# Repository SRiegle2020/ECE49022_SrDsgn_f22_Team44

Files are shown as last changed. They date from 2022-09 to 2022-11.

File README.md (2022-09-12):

# ECE49022_SrDsgn_f22_Team44
ECE49022, Team44, f2022. Biometric "Smart" Watch.
This project aims to display important vital signs to a user in a self-contained watch. The device will specifically track SpO2, heart rate, temperature,
steps walked, and calories consumed. More information to be added to this README.md later.

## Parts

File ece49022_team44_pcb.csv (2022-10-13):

Comment | Designator | Footprint | LCSC PART NUMBER
10n | C1,C2 | Capacitor_SMD:C_0201_0603Metric | C285010
33uF | C19 | Capacitor_Tantalum_SMD:CP_EIA-3528-21_Kemet-B | C723311
22uF | C21,C22 | Capacitor_SMD:C_0402_1005Metric | C415703
0.1uF | C3,C4,C6,C7,C8,C9,C10,C11,C12,C13,C14,C15,C16 | Capacitor_SMD:C_0201_0603Metric | C284966
10uF | C5,C17,C18,C20,C23,C24,C25 | Capacitor_SMD:C_0402_1005Metric | C163694
1N4007 | D1 | Diode_SMD:D_SMA | C727081
LED_Small | D2,D3,D7,D8,D9,D10 | LED_SMD:LED_0603_1608Metric | C72043
BAT60JFILM | D4,D5,D6 | Diode_SMD:D_SOD-323 | C133103
USB_C_Receptacle_USB2.0 | J6 | Connector_USB:USB_C_Receptacle_XKB_U262-16XN-4BVC11 | C2927038
Conn_01x02 | J7,J8 | Connector_JST:JST_PH_S2B-PH-K_1x02_P2.00mm_Horizontal | C265016
SolderJumper_3_Bridged12 | JP1,JP2,JP3,JP4 | Jumper:SolderJumper-3_P1.3mm_Bridged12_Pad1.0x1.5mm
SolderJumper_2_Bridged | JP5 | Jumper:SolderJumper-2_P1.3mm_Bridged2Bar_Pad1.0x1.5mm
1.5uH | L1 | Inductor_SMD:L_0805_2012Metric | C281090
MMBT3904 | Q1 | Package_TO_SOT_SMD:SOT-23 | C8512
BC547 | Q2 | Package_TO_SOT_THT:TO-92_Inline | C713613
10k | R1,R2,R19 | Resistor_SMD:R_0201_0603Metric | C473048
1M | R10 | Resistor_SMD:R_0402_1005Metric | C26083
178k | R11 | Resistor_SMD:R_0402_1005Metric | C185459
680 | R12 | Resistor_SMD:R_0201_0603Metric | C473509
3.3 | R13 | Resistor_SMD:R_0603_1608Metric | C22979
1k | R14 | Resistor_SMD:R_0201_0603Metric | C102683
2.2k | R17 | Resistor_SMD:R_0201_0603Metric | C142018
470 | R18,R20 | Resistor_SMD:R_0201_0603Metric | C473464
150 | R3,R8,R9,R15,R16 | Resistor_SMD:R_0201_0603Metric | C246814
100k | R4,R5 | Resistor_SMD:R_0201_0603Metric | C270364
15k | R6 | Resistor_SMD:R_0201_0603Metric | C473455
220k | R7 | Resistor_SMD:R_0603_1608Metric | C22961
RotaryEncoder_Switch | SW1 | Rotary_Encoder:RotaryEncoder_Alps_EC11E-Switch_Vertical_H20mm_CircularMountingHoles | C370986
Reset | SW2 | Button_Switch_SMD:SW_SPST_Omron_B3FS-101xP | C271753
SW_SPST | SW3 | Button_Switch_SMD:SW_DIP_SPSTx01_Slide_Copal_CHS-01B_W7.62mm_P1.27mm | C3293141
STM32F091RCTx | U1 | Package_QFP:LQFP-64_10x10mm_P0.5mm | C89056
LD1117S33TR_SOT223 | U10 | Package_TO_SOT_SMD:SOT-223-3_TabPin2 | C35879
MCP73831-2-OT | U11,U12 | Package_TO_SOT_SMD:SOT-23-5 | C424093
HDC1080 | U2 | Package_SON:Texas_PWSON-N6 | C82227
PCA9306DC | U4 | Package_SO:VSSOP-8_2.3x2mm_P0.5mm | C33196
PCF8523T | U5 | Package_SO:SOIC-8_3.9x4.9mm_P1.27mm | C2651516
MAX30102 | U6 | OptoDevice:Maxim_OLGA-14_3.3x5.6mm_P0.8mm | C9900007468
MPU-6050 | U7 | Sensor_Motion:InvenSense_QFN-24_4x4mm_P0.5mm | C24112
TPS63000-Q1 | U8 | Package_SON:Texas_DRC0010J_ThermalVias | C523783
LM1117-1.8 | U9 | Package_TO_SOT_SMD:TO-252-2 | C38160

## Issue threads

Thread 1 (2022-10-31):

Display Refresh

SRiegle2020, 2022-10-31:
Must reinit display to refresh screen. Likely due to accelerometer or SpO2 data sampling or processing. Any way to do I2C/DMA with multiple devices on same bus?

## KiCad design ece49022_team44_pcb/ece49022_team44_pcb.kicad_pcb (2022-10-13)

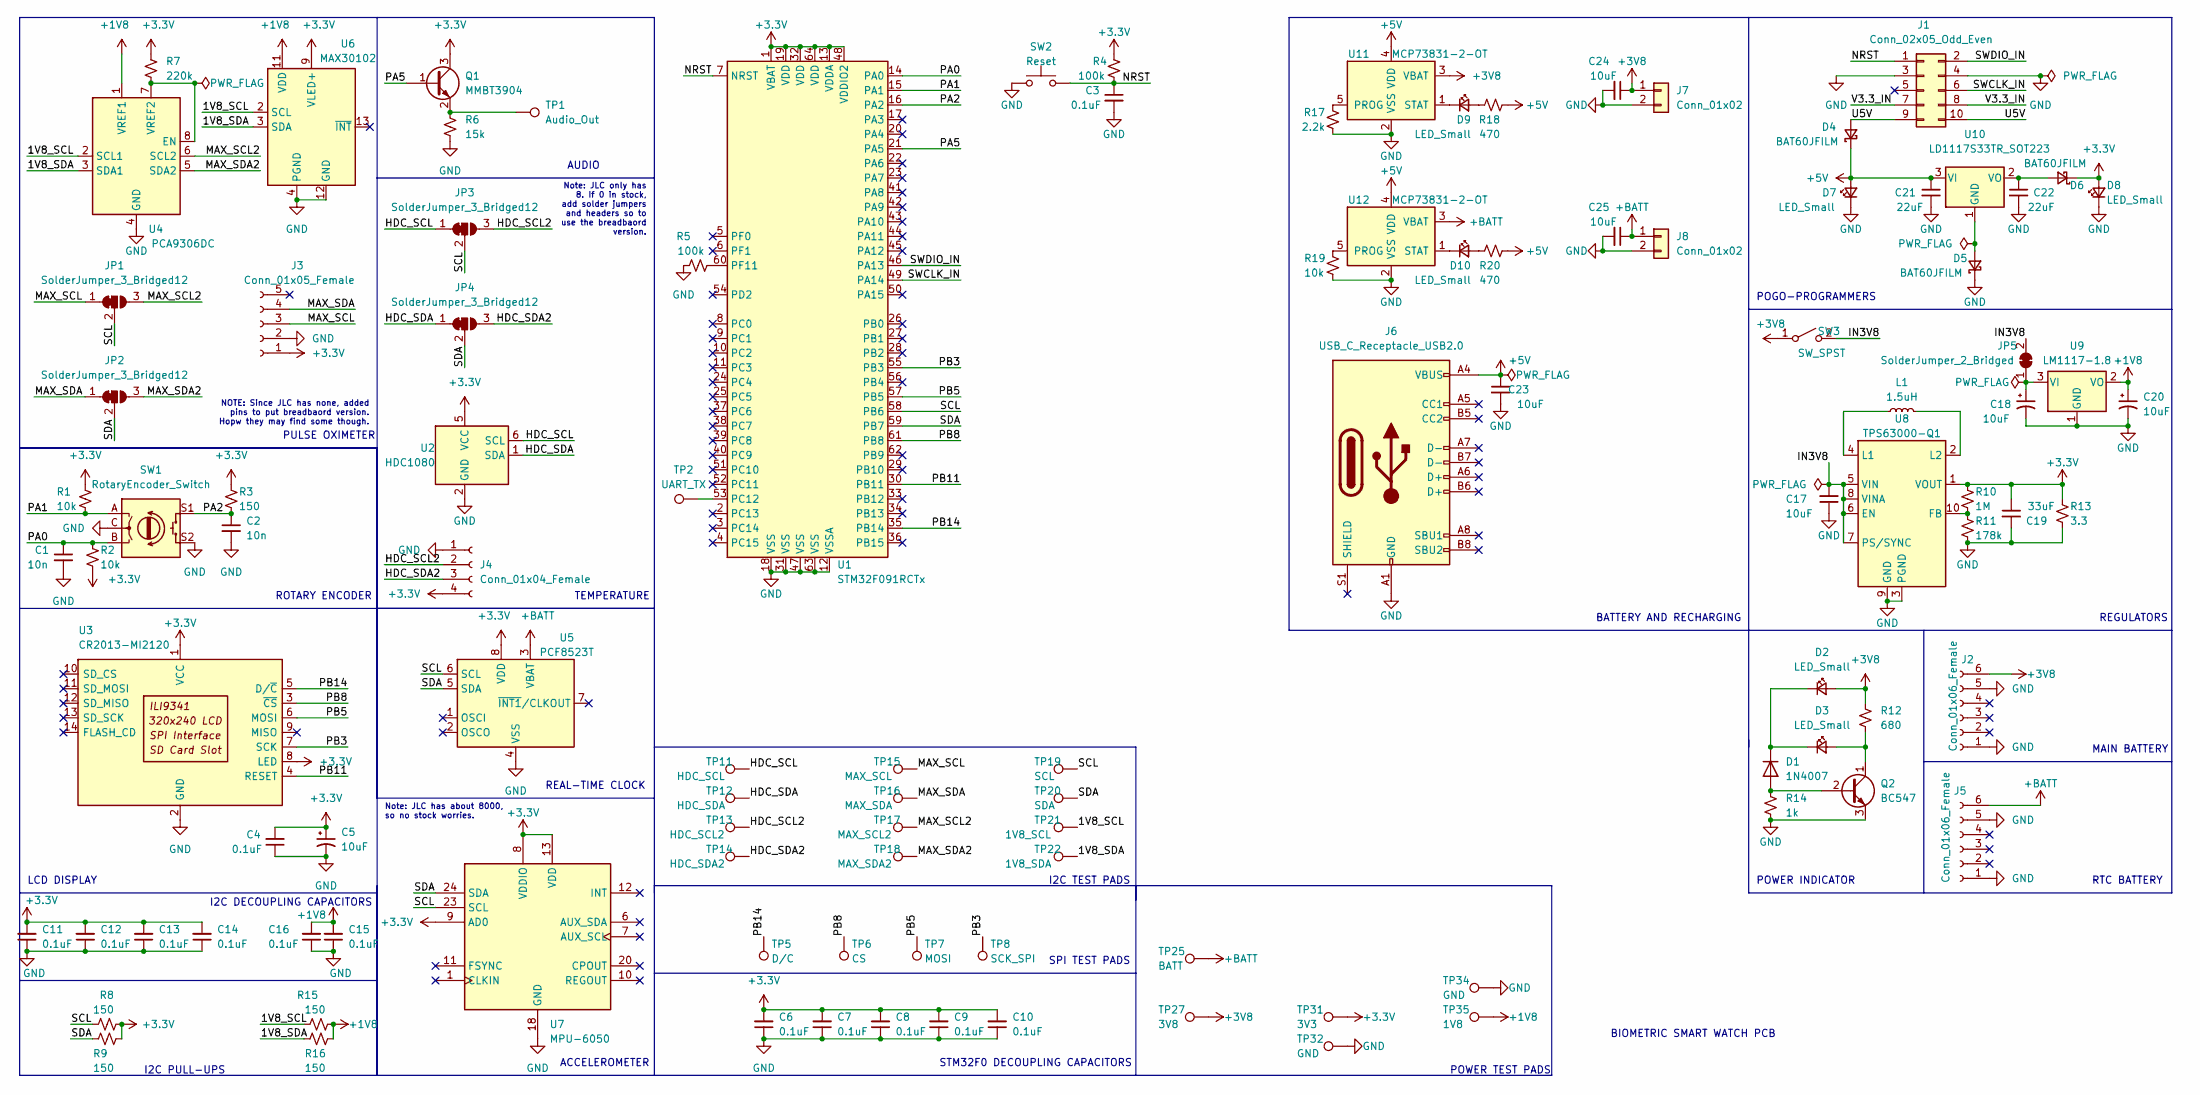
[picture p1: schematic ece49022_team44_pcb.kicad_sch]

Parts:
C1, C2: 10n; C_0201_0603Metric; LCSC C285010
C3, C4, C6, C7, C8, C9, C10, C11, C12, C13, C14, C15, C16: 0.1uF; C_0201_0603Metric; LCSC C284966
C5, C17, C18, C20, C23, C24, C25: 10uF; C_0402_1005Metric; LCSC C163694
C19: 33uF; CP_EIA-3528-21_Kemet-B; LCSC C723311
C21, C22: 22uF; C_0402_1005Metric; LCSC C415703
D1: 1N4007; D_SMA; LCSC C727081
D2: LED_Small; LED_0603_1608Metric; LCSC C72043
D3: LED_Small; LED_0603_1608Metric; LCSC C2286
D4, D5, D6: BAT60JFILM; D_SOD-323; LCSC C133103
D7, D8, D9, D10: LED_Small; LED_0603_1608Metric; LCSC C72038
J1: Conn_02x05_Odd_Even; Tag-Connect_TC2050-IDC-NL_2x05_P1.27mm_Vertical
J2, J5: Conn_01x06_Female; PinSocket_1x06_P2.54mm_Vertical
J3: Conn_01x05_Female; PinSocket_1x05_P2.54mm_Vertical
J4: Conn_01x04_Female; PinHeader_1x04_P2.54mm_Vertical
J6: USB_C_Receptacle_USB2.0; USB_C_Receptacle_XKB_U262-16XN-4BVC11; LCSC C2927038
J7, J8: Conn_01x02; JST_PH_S2B-PH-K_1x02_P2.00mm_Horizontal; LCSC C265016
JP1, JP2, JP3, JP4: SolderJumper_3_Bridged12; SolderJumper-3_P1.3mm_Bridged12_Pad1.0x1.5mm
JP5: SolderJumper_2_Bridged; SolderJumper-2_P1.3mm_Bridged2Bar_Pad1.0x1.5mm
L1: 1.5uH; L_0805_2012Metric; LCSC C281090
Q1: MMBT3904; SOT-23; LCSC C8512
Q2: BC547; TO-92_Inline; LCSC C713613
R1, R2, R19: 10k; R_0201_0603Metric; LCSC C473048
R3, R8, R9, R15, R16: 150; R_0201_0603Metric; LCSC C246814
R4, R5: 100k; R_0201_0603Metric; LCSC C270364
R6: 15k; R_0201_0603Metric; LCSC C473455
R7: 220k; R_0603_1608Metric; LCSC C22961
R10: 1M; R_0402_1005Metric; LCSC C26083
R11: 178k; R_0402_1005Metric; LCSC C185459
R12: 680; R_0201_0603Metric; LCSC C473509
R13: 3.3; R_0603_1608Metric; LCSC C22979
R14: 1k; R_0201_0603Metric; LCSC C102683
R17: 2.2k; R_0201_0603Metric; LCSC C142018
R18, R20: 470; R_0201_0603Metric; LCSC C473464
SW1: RotaryEncoder_Switch; RotaryEncoder_Alps_EC11E-Switch_Vertical_H20mm_CircularMoun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; LCSC C370986
SW2: Reset; SW_SPST_Omron_B3FS-101xP; LCSC C271753
SW3: SW_SPST; SW_DIP_SPSTx01_Slide_Copal_CHS-01B_W7.62mm_P1.27mm; LCSC C3293141
TP1: Audio_Out; TestPoint_Pad_D2.5mm
TP2: UART_TX; TestPoint_Pad_D2.5mm
TP5: D/C; TestPoint_Pad_D2.5mm
TP6: CS; TestPoint_Pad_D2.5mm
TP7: MOSI; TestPoint_Pad_D2.5mm
TP8: SCK_SPI; TestPoint_Pad_D2.5mm
TP11: HDC_SCL; TestPoint_Pad_D2.5mm
TP12: HDC_SDA; TestPoint_Pad_D2.5mm
TP13: HDC_SCL2; TestPoint_Pad_D2.5mm
TP14: HDC_SDA2; TestPoint_Pad_D2.5mm
TP15: MAX_SCL; TestPoint_Pad_D2.5mm
TP16: MAX_SDA; TestPoint_Pad_D2.5mm
TP17: MAX_SCL2; TestPoint_Pad_D2.5mm
TP18: MAX_SDA2; TestPoint_Pad_D2.5mm
TP19: SCL; TestPoint_Pad_D2.5mm
TP20: SDA; TestPoint_Pad_D2.5mm
TP21: 1V8_SCL; TestPoint_Pad_D2.5mm
TP22: 1V8_SDA; TestPoint_Pad_D2.5mm
TP25: BATT; TestPoint_Pad_D2.5mm
TP27: 3V8; TestPoint_Pad_D2.5mm
TP31: 3V3; TestPoint_Pad_D2.5mm
TP32, TP34: GND; TestPoint_Pad_D2.5mm
TP35: 1V8; TestPoint_Pad_D2.5mm
U1: STM32F091RCTx; LQFP-64_10x10mm_P0.5mm; LCSC C89056
U2: HDC1080; Texas_PWSON-N6; LCSC C82227
U3: CR2013-MI2120
U4: PCA9306DC; VSSOP-8_2.3x2mm_P0.5mm; LCSC C33196
U5: PCF8523T; SOIC-8_3.9x4.9mm_P1.27mm; LCSC C2651516
U6: MAX30102; Maxim_OLGA-14_3.3x5.6mm_P0.8mm; LCSC C9900007468
U7: MPU-6050; InvenSense_QFN-24_4x4mm_P0.5mm; LCSC C24112
U8: TPS63000-Q1; Texas_DRC0010J_ThermalVias; LCSC C523783
U9: LM1117-1.8; TO-252-2; LCSC C38160
U10: LD1117S33TR_SOT223; SOT-223-3_TabPin2; LCSC C35879
U11, U12: MCP73831-2-OT; SOT-23-5; LCSC C424093

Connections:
+1V8: C15.2, C16.2, C20.1, R15.1, R16.2, TP35.1, U4.1 (VREF1), U6.11 (VDD), U9.2 (VO)
+3V3: C4.2, C5.1, C6.2, C7.2, C8.2, C9.2, C10.2, C11.2, C12.2, C13.2, C14.2, C19.1, D6.1 (K), D8.2 (A), J3.1, J4.4, Q1.3 (C), R1.2, R2.1, R3.2, R4.1, R7.1, R8.1, R9.2, R10.1, R13.1, TP31.1, U1.1 (VBAT), U1.13 (VDDA), U1.19 (VDD), U1.32 (VDD), U1.48 (VDDIO2), U1.64 (VDD), U2.5 (VCC), U3.1 (VCC), U3.8 (LED), U5.8 (VDD), U6.9 (VLED+), U6.10 (VLED+), U7.8 (VDDIO), U7.9 (AD0), U7.13 (VDD), U8.1 (VOUT)
+3V8: C24.1, D2.2 (A), J2.6, J7.1, R12.1, SW3.1 (A), TP27.1, U11.3 (VBAT)
+5V: C21.1, C23.1, D4.1 (K), D7.2 (A), J6.A4 (VBUS), J6.A9 (VBUS), J6.B4 (VBUS), J6.B9 (VBUS), R18.2, R20.1, U10.3 (VI), U11.4 (VDD), U12.4 (VDD)
+BATT: C25.1, J5.6, J8.1, TP25.1, U5.3 (VBAT), U12.3 (VBAT)
/1V8_SCL: R15.2, TP21.1, U4.2 (SCL1), U6.2 (SCL)
/1V8_SDA: R16.1, TP22.1, U4.3 (SDA1), U6.3 (SDA)
/HDC_SCL: JP3.1 (A), TP11.1, U2.6 (SCL)
/HDC_SCL2: J4.2, JP3.3 (B), TP13.1
/HDC_SDA: JP4.1 (A), TP12.1, U2.1 (SDA)
/HDC_SDA2: J4.3, JP4.3 (B), TP14.1
/IN3V8: C17.2, JP5.2 (B), SW3.2 (B), U8.5 (VIN), U8.6 (EN), U8.7 (PS/SYNC), U8.8 (VINA)
/MAX_SCL: J3.3, JP1.1 (A), TP15.1
/MAX_SCL2: JP1.3 (B), TP17.1, U4.6 (SCL2)
/MAX_SDA: J3.4, JP2.1 (A), TP16.1
/MAX_SDA2: JP2.3 (B), TP18.1, U4.5 (SDA2)
/NRST: C3.1, J1.1, R4.2, SW2.2, U1.7 (NRST)
/PA0: C1.1, R2.2, SW1.B, U1.14 (PA0)
/PA1: R1.1, SW1.A, U1.15 (PA1)
/PA2: C2.1, R3.1, SW1.S1, U1.16 (PA2)
/PA5: Q1.1 (B), U1.21 (PA5)
/PB3: TP8.1, U1.55 (PB3), U3.7 (SCK)
/PB5: TP7.1, U1.57 (PB5), U3.6 (MOSI)
/PB8: TP6.1, U1.61 (PB8), U3.3 (~CS)
/PB11: U1.30 (PB11), U3.4 (RESET)
/PB14: TP5.1, U1.35 (PB14), U3.5 (D/~C)
/SCL: JP1.2 (C), JP3.2 (C), R8.2, TP19.1, U1.58 (PB6), U5.6 (SCL), U7.23 (SCL)
/SDA: JP2.2 (C), JP4.2 (C), R9.1, TP20.1, U1.59 (PB7), U5.5 (SDA), U7.24 (SDA)
/SWCLK_IN: J1.6, U1.49 (PA14)
/SWDIO_IN: J1.2, U1.46 (PA13)
/U5V: D4.2 (A), J1.9, J1.10
/V3.3_IN: J1.7, J1.8
GND: C1.2, C2.2, C3.2, C4.1, C5.2, C6.1, C7.1, C8.1, C9.1, C10.1, C11.1, C12.1, C13.1, C14.1, C15.1, C16.1, C17.1, C18.2, C19.2, C20.2, C21.2, C22.2, C23.2, C24.2, C25.2, D5.1 (K), D7.1 (K), D8.1 (K), J1.3, J1.4, J2.1, J2.5, J3.2, J4.1, J5.1, J5.5, J6.A1 (GND), J6.A12 (GND), J6.B1 (GND), J6.B12 (GND), J7.2, J8.2, Q2.3 (E), R5.2, R6.2, R11.2, R13.2, R14.2, R17.1, R19.1, SW1.C, SW1.S2, SW2.1, TP32.1, TP34.1, U1.12 (VSSA), U1.18 (VSS), U1.31 (VSS), U1.47 (VSS), U1.63 (VSS), U2.2 (GND), U3.2 (GND), U4.4 (GND), U5.4 (VSS), U6.4 (PGND), U6.12 (GND), U7.18 (GND), U8.3 (PGND), U8.9 (GND), U8.11 (PGND), U9.1 (GND), U11.2 (VSS), U12.2 (VSS)
unnamed: C18.1, JP5.1 (A), U9.3 (VI)
unnamed: C22.1, D6.2 (A), U10.2 (VO)
unnamed: D1.1 (A), Q2.2 (B), R14.1
unnamed: D1.2 (K), D2.1 (K), D3.1 (K)
unnamed: D3.2 (A), Q2.1 (C), R12.2
unnamed: D5.2 (A), U10.1 (GND)
unnamed: D9.1 (K), U11.1 (STAT)
unnamed: D9.2 (A), R18.1
unnamed: D10.1 (K), U12.1 (STAT)
unnamed: D10.2 (A), R20.2
unnamed: L1.1, U8.4 (L1)
unnamed: L1.2, U8.2 (L2)
unnamed: Q1.2 (E), R6.1, TP1.1
unnamed: R5.1, U1.60 (PF11)
unnamed: R7.2, U4.7 (VREF2), U4.8 (EN)
unnamed: R10.2, R11.1, U8.10 (FB)
unnamed: R17.2, U11.5 (PROG)
unnamed: R19.2, U12.5 (PROG)
unnamed: TP2.1, U1.53 (PC12)

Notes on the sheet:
POGO-PROGRAMMERS
BATTERY AND RECHARGING
Note: JLC only has 8. If 0 in stock, add solder jumpers and headers so to use the breadbaord version.
TEMPERATURE
REAL-TIME CLOCK
NOTE: Since JLC has none, added pins to put breadbaord version. Hopw they may find some though.
SPI TEST PADS
MAIN BATTERY
RTC BATTERY
I2C PULL-UPS
REGULATORS
ROTARY ENCODER
BIOMETRIC SMART WATCH PCB
I2C TEST PADS
Note: JLC has about 8000, so no stock worries.
POWER INDICATOR
PULSE OXIMETER
LCD DISPLAY
I2C DECOUPLING CAPACITORS
ACCELEROMETER
STM32F0 DECOUPLING CAPACITORS
AUDIO
POWER TEST PADS

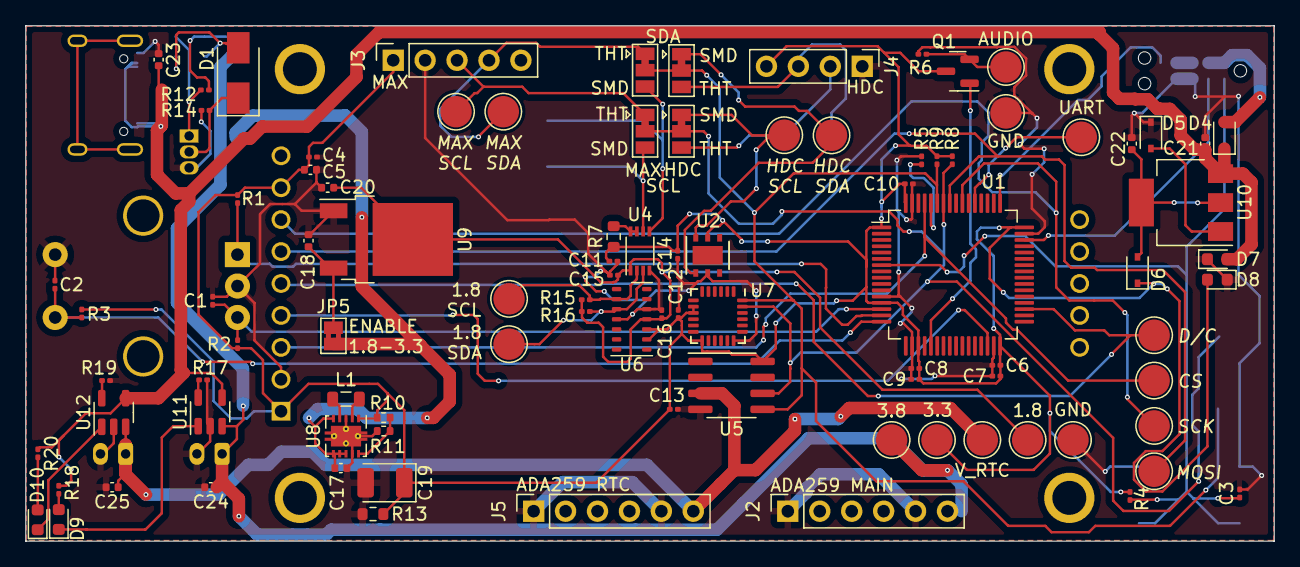
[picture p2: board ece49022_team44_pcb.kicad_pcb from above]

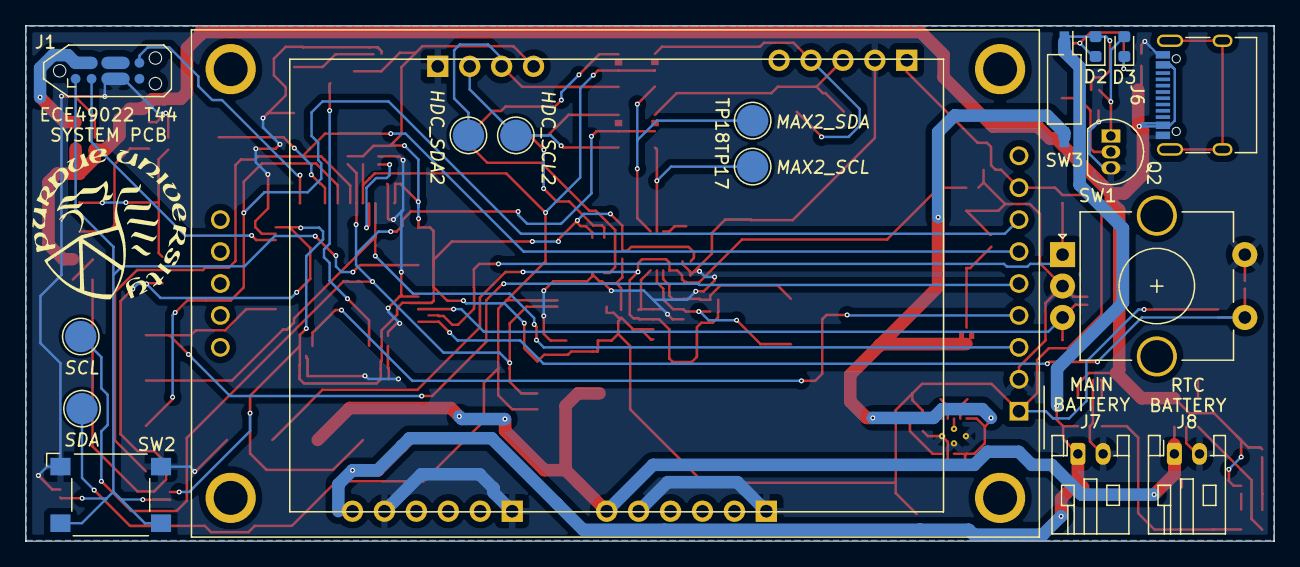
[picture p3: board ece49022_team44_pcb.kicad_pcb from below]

Board: 2 copper layers, 99.3 x 41.0 mm, 110 parts (17 on the bottom side), 52 nets.

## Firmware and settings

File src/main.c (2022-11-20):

//==============================================================================
// DEFINE LIBRARIES
//	Define all libraries to be used for the project.
//==============================================================================
#include "stm32f0xx.h"
#include "i2c.h"
#include "uart.h"
#include "rtc.h"
#include "accelerometer_algorithms.h"
#include "sensors.h"
#include "lcd.h"

#define NO_INIT_GCC __attribute__ ((section (".noinit")))

//==============================================================================
// DEFINE TEST CASES
//	Will be useful if needing UART debugging
//==============================================================================
#define TEST_NONE	 0x00
#define TEST_SPO2 	 0x01
#define TEST_STEP    0x02
#define TEST_EE		 0x04
#define TEST_TIME	 0x10
#define TEST_HR	     0x20
#define TEST_ENCODER 0x40
#define TEST_TEMP	 0x80
#define TEST_AUDIO   0x100
#define TEST_ALL    TEST_SPO2 | TEST_STEP | TEST_EE | TEST_TIME | TEST_HR | TEST_ENCODER | TEST_AUDIO
#define CS_HIGH do { GPIOB->BSRR = GPIO_BSRR_BS_8; } while(0)

//IMPORTANT ==> Change this to change what tests you are running with the UART
int tests = TEST_NONE;

//==============================================================================
// INITIALIZE GLOBAL VARIABLES
//	Initializes all variables that will be used for the project.
//==============================================================================
int   i	  			= 0;
int   prev_spo2 	= 0;
int   spo2  		= 0;
int   prev_HR   	= 0;
int   HR			= 0;
int   prev_tempF 	= 0;
int   tempF  		= 0;
int   prev_steps    = 0;
int   steps 	    = 0;
int   prev_EE_a     = 0;
int   EE_a  		= 0;
int	  prev_hour     = 0;
int   hour			= 0;
int   prev_minute   = 0;
int   minute  		= 0;

static int  ft   NO_INIT_GCC;
static int  inch NO_INIT_GCC;
static int  wgt  NO_INIT_GCC;
static int  age  NO_INIT_GCC;
static char sex  NO_INIT_GCC;
static char string[20];

int mode = 0;

static inline void nano_wait(unsigned int n) {
    asm(    "        mov r0,%0\n"
            "repeat: sub r0,#83\n"
            "        bgt repeat\n" : : "r"(n) : "r0", "cc");
}

void init_exti(void) {
    RCC->AHBENR  |=  RCC_AHBENR_GPIOAEN;            //Clock GPIOA
    GPIOA->MODER &= ~(GPIO_MODER_MODER0             //Configure PA0-2 as inputs
                    | GPIO_MODER_MODER1
                    | GPIO_MODER_MODER2);
    GPIOA->MODER |= GPIO_MODER_MODER5_0;            //Set PA5 to output
    GPIOA->PUPDR &= ~(GPIO_PUPDR_PUPDR0             //Set PUPDR
                    | GPIO_PUPDR_PUPDR1);
    GPIOA->PUPDR |=  (GPIO_PUPDR_PUPDR0_0
                    | GPIO_PUPDR_PUPDR1_0);

    RCC->APB2ENR      |=  RCC_APB2ENR_SYSCFGCOMPEN;         //Clock the interrupt
    SYSCFG->EXTICR[1] &= ~(SYSCFG_EXTICR1_EXTI0_PA
                         | SYSCFG_EXTICR1_EXTI2_PA);        //Set to PA0, PA2
    EXTI->IMR         |=  EXTI_IMR_MR0 | EXTI_IMR_MR2;      //Unmask the interrupts for PA0,PA2
    EXTI->RTSR        |=  EXTI_RTSR_TR0;                    //Set to both rising and falling edge for PA0
    EXTI->FTSR        |=  EXTI_FTSR_TR0;
    EXTI->RTSR        |=  EXTI_RTSR_TR2;                    //Set to rising edge for PA2 (changes when button is RELEASED)

    NVIC->ISER[0] = 1 << EXTI0_1_IRQn;
    NVIC->ISER[0] = 1 << EXTI2_3_IRQn;  //Enable the interrupts
}

//============================================================================
// CHECK_VITALS
//  * Check if user vitals are healthy. If not, play alert tone.
//============================================================================
void check_vitals(void) {
	if((tempF > 991 || (spo2 < 95) || HR < 60 || HR > 100) && spo2 > 0)
		TIM7->CR1 |=  TIM_CR1_CEN;
	else
		TIM7->CR1 &= ~TIM_CR1_CEN;

	if(tests & TEST_AUDIO)
		TIM7->CR1 |=  TIM_CR1_CEN;
	return;
}

//==============================================================================
// EXTI2_3_IRQHandler
//  * Uses an EXTI for PA2 to detect if the encoder button was pressed.
//  * Cycles through the different configuration settings before returning to
//    display.
//==============================================================================
void EXTI2_3_IRQHandler(void) {
    EXTI->PR |= EXTI_PR_PR2;                            //Acknowledge the interrupt
    TIM6->CR1 &= ~TIM_CR1_CEN;
    TIM2->CR1 &= ~TIM_CR1_CEN;
    mode++;
    nano_wait(100000000); //Add a delay to account for "double presses"
    //Change modes
    if(mode == 1) {
        LCD_Setup();
        LCD_DrawFillRectangle(0,214,319,239,WHITE);
        LCD_DrawString(10,219,BLACK,BLACK,"--ADJUST HGT (FEET)--",16,0xff);
        sprintf(string,"%d'",ft);
        LCD_DrawString(280,219,BLACK,BLACK,string,16,0xff);
    } else if(mode == 2) {
        LCD_DrawFillRectangle(0,214,319,239,WHITE);
        LCD_DrawString(10,219,BLACK,BLACK,"--ADJUST HGT (INCH)--",16,0xff);
        sprintf(string,"%2d'",inch);
        LCD_DrawString(280,219,BLACK,BLACK,string,16,0xff);
    } else if(mode == 3) {
        LCD_DrawFillRectangle(0,214,319,239,WHITE);
        LCD_DrawString(10,219,BLACK,BLACK,"--ADJUST WGT--",16,0xff);
        sprintf(string,"%d lbs",wgt);
        LCD_DrawString(260,219,BLACK,BLACK,string,16,0xff);
    } else if(mode == 4) {
        LCD_DrawFillRectangle(0,214,319,239,WHITE);
        LCD_DrawString(10,219,BLACK,BLACK,"--ADJUST AGE--",16,0xff);
        sprintf(string,"%d yrs",age);
        LCD_DrawString(260,219,BLACK,BLACK,string,16,0xff);
    } else if(mode == 5) {
        LCD_DrawFillRectangle(0,214,319,239,WHITE);
        LCD_DrawString(10,219,BLACK,BLACK,"--ADJUST SEX--",16,0xff);
        sprintf(string,"%c",sex);
        LCD_DrawString(280,219,BLACK,BLACK,string,16,0xff);
    } else if(mode == 6) {
        LCD_DrawFillRectangle(0,214,319,239,WHITE);
        LCD_DrawString(10,219,BLACK,BLACK,"--ADJUST TIME (HRS)--",16,0xff);
        sprintf(string,"%02d:%02d",hour,minute);
        LCD_DrawString(280,219,BLACK,BLACK,string,16,0xff);
    } else if(mode == 7) {
        LCD_DrawFillRectangle(0,214,319,239,WHITE);
        LCD_DrawString(10,219,BLACK,BLACK,"--ADJUST TIME (MIN)--",16,0xff);
        sprintf(string,"%02d:%02d",hour,minute);
        LCD_DrawString(280,219,BLACK,BLACK,string,16,0xff);

    //If done editing, redraw entire thing
    } else {
        mode = 0;
        set_hours(hour);
        set_minutes(minute);
        LCD_Setup();
        LCD_Clear(0x18e4);
        sprintf(string,"%02d:%02d",hour,minute);
        LCD_DrawString(104,96,0xf924,BLACK,string,48,0xff);

        LCD_DrawFillRectangle(0, 0, 320, 6, 0xa65b);
        LCD_DrawFillRectangle(0, 0, 6, 240, 0xa65b);
        LCD_DrawFillRectangle(0, 234, 320, 240, 0xa65b);
        LCD_DrawFillRectangle(314, 0, 320, 240, 0xa65b);

        sprintf(string,"SpO2");
        LCD_DrawString(10 + 112,10,WHITE,WHITE,string,16,0xff);
        sprintf(string,"HR");
        LCD_DrawString(10 + 180,10,WHITE,WHITE,string,16,0xff);

        if(spo2 != -1) {
            sprintf(string,"%-3d%%",spo2);
            LCD_DrawString(10 + 112,10 + 16,WHITE,WHITE,string,16,0xff);
            sprintf(string,"%-3d",HR);
            LCD_DrawString(10 + 180,10+16,WHITE,WHITE,string,16,0xff);
        } else {
            LCD_DrawString(10 + 112,10+16,WHITE,WHITE,"N/A",16,0xff);
            LCD_DrawString(10 + 180,10+16,WHITE,WHITE,"N/A",16,0xff);
        }

        sprintf(string,"TEMP");
        LCD_DrawString(10 + 235,10,WHITE,WHITE,string,16,0xff);
        sprintf(string,"%d.%d^F",tempF/10,tempF%10);
        LCD_DrawString(10 + 235,10 + 16,WHITE,WHITE,string,16,0xff);

        sprintf(string,"STEPS");
        LCD_DrawString(10,10,WHITE,WHITE,string,16,0xff);
        sprintf(string,"%-5d",steps);
        LCD_DrawString(10,10+16,WHITE,WHITE,string,16,0xff);

        sprintf(string,"EE");            //Truncate to Int
        LCD_DrawString(10 + 64,10,WHITE,WHITE,string,16,0xff);
        sprintf(string,"%-4d",EE_a/100);
        LCD_DrawString(10 + 64,10 + 16,WHITE,WHITE,string,16,0xff);

        sprintf(string,"HEIGHT");
        LCD_DrawString(100,213,WHITE,WHITE,string,16,0xff);
        sprintf(string,"%d'%2d\"",ft,inch);
        LCD_DrawString(100,197,WHITE,WHITE,string,16,0xff);

        sprintf(string,"WEIGHT",wgt);
        LCD_DrawString(10,213,WHITE,WHITE,string,16,0xff);
        sprintf(string,"%-3dlbs",wgt);
        LCD_DrawString(10,197,WHITE,WHITE,string,16,0xff);

        sprintf(string,"Age");
        LCD_DrawString(200,213,WHITE,WHITE,string,16,0xff);
        sprintf(string,"%-3d",age);
        LCD_DrawString(200,197,WHITE,WHITE,string,16,0xff);

        sprintf(string,"Sex");
        LCD_DrawString(280,213,WHITE,WHITE,string,16,0xff);
        sprintf(string,"%c",sex);
        LCD_DrawString(280,197,WHITE,WHITE,string,16,0xff);

        //Update previous values
        prev_minute = minute;
        prev_spo2   = spo2;
        prev_HR     = HR;
        prev_tempF  = tempF;
        prev_steps  = steps;
        prev_EE_a   = EE_a;

        TIM6->CR1 |= TIM_CR1_CEN;
        TIM2->CR1 |= TIM_CR1_CEN;
    }

    //Used for UART Debugging
    if(tests & TEST_ENCODER)
        printf("Button Released\n");

}

//==============================================================================
// EXTI0_1_IRQHandler
//  * Uses an EXTI for PA0 and PA1 to detect whether encoder is rotated.
//  * Changes settings based off of different modes.
//==============================================================================
void EXTI0_1_IRQHandler(void) {
    EXTI->PR |= EXTI_PR_PR0; //Acknowledge the interrupt
    int increment;
    if(!((GPIOA->IDR & 0x3)%3))
        increment = 1;
    else
        increment = -1;

    if(mode == 1) {
        ft += increment;
        //Keep values in the range [0,9]
        if(ft < 0)
            ft = 0;
        if(ft > 9)
            ft = 9;
        LCD_DrawFillRectangle(0,214,319,239,WHITE);
        LCD_DrawString(10,219,BLACK,BLACK,"--ADJUST HGT (FEET)--",16,0xff);
        sprintf(string,"%d'",ft);
        LCD_DrawString(280,219,BLACK,BLACK,string,16,0xff);
        RTC->BKP0R = ft;
    } else if(mode == 2) {
        inch += increment;
        //Keep values in the range [0,12)
        if(inch < 0)
            inch = 0;
        if(inch > 11)
            inch = 11;
        LCD_DrawFillRectangle(0,214,319,239,WHITE);
        LCD_DrawString(10,219,BLACK,BLACK,"--ADJUST HGT (INCH)--",16,0xff);
        sprintf(string,"%2d'",inch);
        LCD_DrawString(280,219,BLACK,BLACK,string,16,0xff);
        RTC->BKP1R = inch;
    } else if(mode == 3) {
        wgt += increment;
        if(wgt < 50)  //Keep values in range [50,600] to account for kids and
                      //very big people
            wgt = 50;
        if(wgt > 600)
            wgt = 600;
        LCD_DrawFillRectangle(0,214,319,239,WHITE);
        LCD_DrawString(10,219,BLACK,BLACK,"--ADJUST WGT--",16,0xff);
        sprintf(string,"%d lbs",wgt);
        LCD_DrawString(260,219,BLACK,BLACK,string,16,0xff);
        RTC->BKP2R = wgt;
    } else if(mode == 4) {
        age += increment;
        if(age < 0)     //Limit ages to [0,110]
            age = 0;
        if(age > 110)
            age = 110;
        LCD_DrawFillRectangle(0,214,319,239,WHITE);
        LCD_DrawString(10,219,BLACK,BLACK,"--ADJUST AGE--",16,0xff);
        sprintf(string,"%d yrs",age);
        LCD_DrawString(260,219,BLACK,BLACK,string,16,0xff);
        RTC->BKP3R = age;
    } else if(mode == 5) {
        if(sex == 'M')
            sex = 'F';
        else
            sex = 'M';
        LCD_DrawFillRectangle(0,214,319,239,WHITE);
        LCD_DrawString(10,219,BLACK,BLACK,"--ADJUST SEX--",16,0xff);
        sprintf(string,"%c",sex);
        LCD_DrawString(280,219,BLACK,BLACK,string,16,0xff);
        RTC->BKP4R = sex;
    } else if(mode == 6) {
        hour += increment;
        if(hour > 23)
            hour = 0;
        if(hour < 0)
            hour = 23;
        LCD_DrawFillRectangle(0,214,319,239,WHITE);
        LCD_DrawString(10,219,BLACK,BLACK,"--ADJUST TIME (HRS)--",16,0xff);
        sprintf(string,"%02d:%02d",hour,minute);
        LCD_DrawString(280,219,BLACK,BLACK,string,16,0xff);
        //TimeHr
    } else if(mode == 7) {
        //TimMin
        minute += increment;
        if(minute > 59)
            minute = 0;
        if(minute < 0)
            minute = 59;
        LCD_DrawFillRectangle(0,214,319,239,WHITE);
        LCD_DrawString(10,219,BLACK,BLACK,"--ADJUST TIME (MIN)--",16,0xff);
        sprintf(string,"%02d:%02d",hour,minute);
        LCD_DrawString(280,219,BLACK,BLACK,string,16,0xff);
    }

    if(tests & TEST_ENCODER) {
        if(!((GPIOA->IDR & 0x3)%3))
            printf("Clockwise\n");
        else
            printf("Counter-clockwise\n");
    }
}

void init_tim7(void) {
	//Set to 660Hz audio (toggle at 330Hz)
    RCC->APB1ENR |= RCC_APB1ENR_TIM7EN;
    TIM7->PSC = 360 - 1;
    TIM7->ARR = 101 - 1;
    TIM7->DIER |= TIM_DIER_UIE;
    NVIC->ISER[0] |= 1 << TIM7_IRQn;
}

//==============================================================================
// Simulates a crummy sine wave
//==============================================================================
void TIM7_IRQHandler(void) {
	TIM7->SR &= ~TIM_SR_UIF; //Acknowledge Interrupt
	if(GPIOA->ODR & 0x20)
		GPIOA->ODR &= ~0x20;
	else
		GPIOA->ODR |=  0x20;
}
//==============================================================================
// TIM6_DAC_IRQHandler
//  * Samples all sensors @ 30Hz.
//  * Also has UART debugging.
//==============================================================================
void TIM6_DAC_IRQHandler(void) {
    //Get SpO2 Data
    pulseox_check();
    spo2 = get_spo2();
    HR   = get_HR();

    //Get Steps
    accel_sample();
    if(detect_step())
    	steps++;

    //Once a minute, update the EE counter
    if(i == 30*60) {
    	EE_a = EE_IEEE(wgt);
        i = 0;
    }

    //Get the temperature
    tempF = get_temp();
    if(tests & TEST_TEMP)
    	printf("Temp: %d.%dF\n",tempF/10,tempF%10);

    //Get the time
    if(!(i%10)) {//Update @ 3Hz (no need to continually update it)
    	hour   = get_hour();
    	minute = get_minutes();
    }

    check_vitals();

    //PRINT TEST CASES TO UART
    if(tests & TEST_SPO2) {
    	if(spo2 == -1)
    		printf("WRIST NOT DETECTED\n");
		else
			printf("SPO2:  %d%%\n",spo2);
    }
    if(tests & TEST_STEP)
    	printf("STEPS: %d\n",steps);
    if(tests & TEST_EE)
    	printf("EE:    %.2f\n",(float)EE_a/100);
    if(tests & TEST_TIME)
    	printf("TIME:  %02d:%02d\n",hour,minute);
    if(tests & TEST_HR)
    	printf("HR:    %d BPM\n",HR);
    i++; //Increment the counter

    TIM6->SR &= ~TIM_SR_UIF; //Acknowledge Interrupt
}


void init_tim6(void) {
	//Set to 30Hz sampling
    RCC->APB1ENR |= RCC_APB1ENR_TIM6EN;
    TIM6->PSC = 1000 - 1;
    TIM6->ARR = 1600 - 1;
    TIM6->DIER |= TIM_DIER_UIE;
    TIM6->CR1 |= TIM_CR1_CEN;
    NVIC->ISER[0] |= 1 << TIM6_DAC_IRQn;
}

//==============================================================================
// TIM2_IRQHandler
//  * Updates display once every 5 seconds.
//  * Wanted to continually update if changes detected, but sensors take so long
//    that LCD won't work without pausing timers, resetting the display, and
//    redrawing everything.
//==============================================================================
void TIM2_IRQHandler(void) {
	TIM6->CR1 &= ~TIM_CR1_CEN;
    TIM2->SR &= ~TIM_SR_UIF; //Acknowledge Interrupt
    if(minute != prev_minute | prev_spo2 != spo2 | prev_HR != HR | tempF != prev_tempF | prev_steps != steps | prev_EE_a != EE_a) {
    	while(SPI1->SR & SPI_SR_BSY);
    	LCD_Setup();
    	LCD_Clear(0x18e4);
		sprintf(string,"%02d:%02d",hour,minute);
		while(SPI1->SR & SPI_SR_BSY);
		LCD_DrawString(104,96,0xf924,BLACK,string,48,0xff);

		LCD_DrawFillRectangle(0, 0, 320, 6, 0xa65b);
		LCD_DrawFillRectangle(0, 0, 6, 240, 0xa65b);
		LCD_DrawFillRectangle(0, 234, 320, 240, 0xa65b);
		LCD_DrawFillRectangle(314, 0, 320, 240, 0xa65b);

		//Reset values at midnight
		if(midnight()) {
		    steps = 0;
		    EE_a  = 0;
		}
		sprintf(string,"SpO2");
		LCD_DrawString(10 + 112,10,WHITE,WHITE,string,16,0xff);
		sprintf(string,"HR");

		LCD_DrawString(10 + 180,10,WHITE,WHITE,string,16,0xff);
		if(spo2 != -1) {
			sprintf(string,"%-3d%%",spo2);
			LCD_DrawString(10 + 112,10 + 16,WHITE,WHITE,string,16,0xff);
		    sprintf(string,"%-3d",HR);
		    LCD_DrawString(10 + 180,10+16,WHITE,WHITE,string,16,0xff);
		} else {
		    LCD_DrawString(10 + 112,10+16,WHITE,WHITE,"N/A",16,0xff);
		    LCD_DrawString(10 + 180,10+16,WHITE,WHITE,"N/A",16,0xff);
		}

		sprintf(string,"TEMP");
		LCD_DrawString(10 + 235,10,WHITE,WHITE,string,16,0xff);
		sprintf(string,"%d.%d^F",tempF/10,tempF%10);
		LCD_DrawString(10 + 235,10 + 16,WHITE,WHITE,string,16,0xff);

		sprintf(string,"STEPS");
		LCD_DrawString(10,10,WHITE,WHITE,string,16,0xff);
		sprintf(string,"%-5d",steps);
		LCD_DrawString(10,10+16,WHITE,WHITE,string,16,0xff);

		sprintf(string,"EE");            //Truncate to Int
		LCD_DrawString(10 + 64,10,WHITE,WHITE,string,16,0xff);
		sprintf(string,"%-4d",EE_a/100);
		LCD_DrawString(10 + 64,10 + 16,WHITE,WHITE,string,16,0xff);


		sprintf(string,"HEIGHT");
		LCD_DrawString(100,213,WHITE,WHITE,string,16,0xff);
		sprintf(string,"%d'%2d\"",ft,inch);
		LCD_DrawString(100,197,WHITE,WHITE,string,16,0xff);

		sprintf(string,"WEIGHT",wgt);
		LCD_DrawString(10,213,WHITE,WHITE,string,16,0xff);
		sprintf(string,"%-3dlbs",wgt);
		LCD_DrawString(10,197,WHITE,WHITE,string,16,0xff);

		sprintf(string,"Age");
		LCD_DrawString(200,213,WHITE,WHITE,string,16,0xff);
		sprintf(string,"%-3d",age);
		LCD_DrawString(200,197,WHITE,WHITE,string,16,0xff);

		sprintf(string,"Sex");
		LCD_DrawString(280,213,WHITE,WHITE,string,16,0xff);
		sprintf(string,"%c",sex);
		LCD_DrawString(280,197,WHITE,WHITE,string,16,0xff);

		prev_minute = minute;
		prev_spo2   = spo2;
		prev_HR		= HR;
		prev_tempF  = tempF;
		prev_steps  = steps;
		prev_EE_a   = EE_a;

		//LCD_DrawString(0,239-32,WHITE,WHITE,"HELLO THERE",32,0xff);
    }
    TIM6->CR1 |=  TIM_CR1_CEN;
}

void init_tim2(void) {
	//Set to update display every 5 seconds
    RCC->APB1ENR |= RCC_APB1ENR_TIM2EN;
    TIM2->PSC = 4800  - 1;
    TIM2->ARR = 50000 - 1;
    TIM2->DIER |= TIM_DIER_UIE;
    TIM2->CR1  |= TIM_CR1_CEN;
    NVIC->ISER[0] |= 1 << TIM2_IRQn;
}

void init_lcd_spi() {
    RCC->AHBENR |= RCC_AHBENR_GPIOBEN;
    GPIOB->MODER &= ~0x30c30000;
    GPIOB->MODER |=  0x10410000;
    init_spi1_slow();       //No need to redefine these two
    sdcard_io_high_speed(); //Both already exist in wavPlayer.c
}

void init_spi1_slow() {
    RCC->APB2ENR  |=  RCC_APB2ENR_SPI1EN; //ENABLE SPI1 RCC CLOCK
    RCC->AHBENR   |=  RCC_AHBENR_GPIOBEN; //ENABLE GPIOB
    GPIOB->MODER  &= ~0XFC0;              //CLEAR PB3,4,5
    GPIOB->MODER  |=  0XA80;              //SET PB3,4,5 TO ALTFN
    GPIOB->AFR[0] &= ~0XFFF000;           //SET AFR3,4,5 TO AF0

    SPI1->CR1 &= ~SPI_CR1_SPE; //DISABLE SPI
    SPI1->CR1 |= SPI_CR1_BR;   //SET BAUD RATE
    SPI1->CR1 |= SPI_CR1_MSTR; //MASTER MODE
    SPI1->CR2  = SPI_CR2_DS_2 | SPI_CR2_DS_1 | SPI_CR2_DS_0; //SET TO 8 BIT
    SPI1->CR2 |= SPI_CR2_SSOE | SPI_CR2_NSSP; //OTHER STUFF
    SPI1->CR2 |= SPI_CR2_FRXTH;
    SPI1->CR1 |= SPI_CR1_SSM | SPI_CR1_SSI;
    SPI1->CR1 |= SPI_CR1_SPE;  //ENABLE
}

void sdcard_io_high_speed() {
    SPI1->CR1 &= ~SPI_CR1_SPE;
    SPI1->CR1 &= ~SPI_CR1_BR;
    //SPI1->CR1 |=  SPI_CR1_BR_0;
    SPI1->CR1 |=  SPI_CR1_SPE;
}

void internal_clock()
{
    /* Disable HSE to allow use of the GPIOs */
    RCC->CR &= ~RCC_CR_HSEON;

    /* Enable Prefetch Buffer and set Flash Latency */
    FLASH->ACR = FLASH_ACR_PRFTBE | FLASH_ACR_LATENCY;

    /* HCLK = SYSCLK */
    RCC->CFGR |= (uint32_t)RCC_CFGR_HPRE_DIV1;

    /* PCLK = HCLK */
    RCC->CFGR |= (uint32_t)RCC_CFGR_PPRE_DIV1;

    /* PLL configuration = (HSI/2) * 12 = ~48 MHz */
    RCC->CFGR &= (uint32_t)((uint32_t)~(RCC_CFGR_PLLSRC | RCC_CFGR_PLLXTPRE | RCC_CFGR_PLLMULL));
    RCC->CFGR |= (uint32_t)(RCC_CFGR_PLLSRC_HSI_Div2 | RCC_CFGR_PLLXTPRE_PREDIV1 | RCC_CFGR_PLLMULL12);

    /* Enable PLL */
    RCC->CR |= RCC_CR_PLLON;

    /* Wait till PLL is ready */
    while((RCC->CR & RCC_CR_PLLRDY) == 0)
    {
    }

    /* Select PLL as system clock source */
    RCC->CFGR &= (uint32_t)((uint32_t)~(RCC_CFGR_SW));
    RCC->CFGR |= (uint32_t)RCC_CFGR_SW_PLL;

    /* Wait till PLL is used as system clock source */
    while ((RCC->CFGR & (uint32_t)RCC_CFGR_SWS) != (uint32_t)RCC_CFGR_SWS_PLL)
    {
    }
}


//=============================================================================
// SAMPLE MAIN
//	Initializes all ICs.
//	Then, initialize the timer when everything is configured.
//=============================================================================
int main(void)
{
	//If a Power Cycle, give initial values
	//Otherwise, the "noinit" attribute will keep values the same with reset
	internal_clock();
	if(RCC->CSR & RCC_CSR_PORRSTF) {
		ft   = 5;
		inch = 11;
		wgt  = 125;
		age  = 20;
		sex  = 'M';
		RCC->CSR |= RCC_CSR_RMVF;
	}
	if(ft < 0 || ft>9)
		ft = 5;
	if(inch < 0 || inch > 11)
		inch = 11;
	if(wgt < 0 || wgt > 600)
		wgt = 125;
	if(age < 0 || age > 110)
		age = 20;
	if(sex != 'M' || sex != 'F')
		sex = 'M';

    LCD_Setup();
    LCD_Clear(BLACK);

	init_i2c();
	init_usart5();
	pulseox_setup();
	init_temp_sensor();
	init_accelerometer();
	init_exti();
	init_watch();

    init_tim6();
    init_tim2();
    init_tim7();
	while(1);
}

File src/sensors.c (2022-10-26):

#include "stm32f0xx.h"
#include <stdio.h>
#include "i2c.h"
#include "sensors.h"

#include "uart.h"

//============================================================================
// DEFINITIONS FOR DEVICE ADDRESSES
//  * This just includes the definitions for the device addresses.
//============================================================================
#define ACCELEROMETER_ADDR 	0x69 //Since MPU6050 has the same address as the PCF8523, we have to set the A0 pin on the MPU6050 HIGH so both can be on the same I2C bus
#define PULSEOX_ADDR 		0x57
#define HDC_ADDR 			0x40

//============================================================================
// TEMP_WRITE
//  * Send data to the temp sensor
//  * Used mainly for configuration
//============================================================================
void temp_write(uint8_t reg0, uint8_t val0, uint8_t val1) {
	uint8_t temp_writedata[4] = {reg0,val0,val1};
	i2c_senddata(HDC_ADDR, temp_writedata,3);
}

//============================================================================
// TEMP_SIMPLE_READ
//  * Read a single byte from the temp sensor.
//============================================================================
uint8_t temp_simple_read(uint8_t reg) {
    uint8_t temp_data[1] = {reg};
    i2c_recvdata_noP(HDC_ADDR, temp_data, 1);
    return I2C1->RXDR & 0xff;
}

//============================================================================
// TEMP_READ_ARRAY
//  * Read individual data from the temp sensor.
//  * Result is stored into the data buffer
//============================================================================
void temp_read_array(uint8_t loc, char data[], uint8_t len) {
    uint8_t reg[1] = { loc };

    i2c_recvdata_noP_array(HDC_ADDR,data,len,reg);              //Read data
}

//============================================================================
// INIT_TEMP_SENSOR
//  * Configures the temperature sensor to measure temperature only
//	  (not humidity).
//============================================================================
void init_temp_sensor(void) {
	temp_write(0x2,0x0,0x0);
}

static inline void nano_wait(unsigned int n) {
    asm(    "        mov r0,%0\n"
            "repeat: sub r0,#83\n"
            "        bgt repeat\n" : : "r"(n) : "r0", "cc");
}

//============================================================================
// GET_TEMP
//	* Reads temperature and returns in F.
//    NOTE: Sensor returns 10*tempF. Also, needs a nanowait between setting
//          the pointer and reading the value.
//============================================================================
int get_temp(void) {
	i2c_senddata(HDC_ADDR,0x02,1); //Set pointer
	nano_wait(20000000);		   //Datasheet requires waiting 20ms
	char temp_arr[2];
	i2c_recvdata_P(HDC_ADDR,temp_arr,2);
	int   temp_16 = (temp_arr[0] << 8) | (temp_arr[1]);
	float temp_C  = ((float)temp_16 /(float)65536) * 160 - 40; //Convert 16bit to C
	return(18*temp_C + 320);									   //Convert to 10*F
}

//============================================================================
// PULSEOX_WRITE
//  * Send data to the pulse-oximeter
//  * Used mainly for configuration
//============================================================================
void pulseox_write(uint8_t reg, uint8_t val) {
	uint8_t pulseox_writedata[2] = {reg, val};
	i2c_senddata(PULSEOX_ADDR, pulseox_writedata,2);
}

//============================================================================
// PULSEOX_SIMPLE_READ
//  * Read a single byte from the pulse oximeter.
//============================================================================
uint8_t pulseox_simple_read(uint8_t reg) {
    uint8_t pulseox_data[1] = {reg};
    i2c_recvdata_noP(PULSEOX_ADDR, pulseox_data, 1);
    return I2C1->RXDR & 0xff;
}

//============================================================================
// PULSEOX_READ_ARRAY
//  * Read individual data from the pulse oximeter.
//  * Result is stored into the data buffer
//============================================================================
void pulseox_read_array(uint8_t loc, char data[], uint8_t len) {
    uint8_t reg[1] = { loc };
    i2c_recvdata_noP_array(PULSEOX_ADDR,data,len,reg);              //Read data
}

//============================================================================
// PULSEOX_SETUP
//  * Resets pulse ox
//  * Sets to average 32 samples per FIFO sample, roll-over data
//============================================================================
void pulseox_setup(void) {
	pulseox_write(0x09,0x40); 	//Reset
	pulseox_write(0x08,0x70); 	//Average 8 samples per FIFO sample, roll-over data
	pulseox_write(0x09,0x03); 	//Set to SpO2 mode (RED and IR) -> 2 active LEDs
	pulseox_write(0x0a,0x27); 	//Set to 4096nA range, 100 samples/second, and 411us width
	pulseox_write(0x0c,0x1f);	//Set LEDs to 6.2mA power (about ~4" detection)
	pulseox_write(0x0d,0x1f);

	pulseox_write(0x11,0x21);   //Set Time Slots (Slot 1 -> Red; Slot 2 -> Infrared)

	//Clear FIFO
	pulseox_write(0x04,0x00);
	pulseox_write(0x05,0x00);
	pulseox_write(0x06,0x00);
}

int led_arr[30*5*2];
float r;

//============================================================================
// PULSEOX_CHECK
//  * THEORETICALLY checks data from the FIFO.
//  * Adapted from https://github.com/sparkfun/SparkFun_MAX3010x_Sensor_Library
//    (SPARKFUN's OPEN SOURCE ARDUINO LIBRARY)
//============================================================================
void pulseox_check(void)
{
    //Read register FIDO_DATA in (3-byte * number of active LED) chunks
    //Until FIFO_RD_PTR = FIFO_WR_PTR
    uint8_t readPointer  = pulseox_simple_read(0x06);
    uint8_t writePointer = pulseox_simple_read(0x04);

    int numberOfSamples = 0;

    //Do we have new data?
    //Calculate the number of readings we need to get from sensor
    numberOfSamples = writePointer - readPointer;
    if (numberOfSamples < 0) numberOfSamples += 32; //Wrap condition

    //We now have the number of readings, now calc bytes to read
    //For this example we are just doing Red and IR (3 bytes each)
    //3 bytes per sample, 2 LEDs
    char pulseox_buf[6];
    pulseox_read_array(0x07, pulseox_buf,6);

    int IR = (pulseox_buf[0] << 16) | (pulseox_buf[1] << 8) | (pulseox_buf[2]);
    IR &= 0x3ffff;
    int Rd = (pulseox_buf[3] << 16) | (pulseox_buf[4] << 8) | (pulseox_buf[5]);
    Rd &= 0x3ffff;
    //printf("R%6d  I%6d\n",Rd,IR);

    for(int i = 300; i > 0; i -= 2) {
    	led_arr[i]   = led_arr[i-2];
    	led_arr[i-1] = led_arr[i-3];
    }
    led_arr[0] = Rd;
    led_arr[1] = IR;
}
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

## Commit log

2022-09-12 UART Libraries
    This is just a UART library to allow us to view variables on the serial port. It will only be used for debugging and will not be a part of the final project.
2022-09-14 BROKEN MAIN!
    Adding this so that I can MELD with old I2C functions, maybe find error in code.
    [main.c]
2022-09-16 I2C and Sensors Libraries
    Added working libraries to use I2C and sensors. Sensor for accelerometer already added.
2022-09-17 All Accelerometer Stuff Working
    I got all the stuff for the accelerometer working, including accelerometer_X(), accerelometer_Y(), and accelerometer_Z() functions that return acceleration in each of those directions. The problems include a broken sensor and the fact that the MPU6050 and AHT10 have the same address.
    [main.c, sensors.c]
2022-09-18 RTC Commands, Fixed I2C
    Added most RTC commands (except one for generating an interrupt; will be added in the future). Also added I2C functionality for both forms of I2C reading (with vs without a stop).
    [i2c.c, main.c, rtc.c]
2022-09-18 Updated sensors.h
    Includes new sensors.h
2022-09-18 Updated sensors.c for New I2C Fixes
    Since I2C had to be fixed to use two different I2C protocols for reading (one with and one without a STOP), had to do some minor fixes to the sensors.c file.
2022-09-18 Updated to Account for New I2C
    Adjusted to work with updated I2C algorithms
2022-09-19 Rough Algorithms
    Incorporated rough algorithms for BMR, steps, and EE. Steps assumes a 100Hz sampling rate and returns a 1 if a rising edge (step) is detected and 0 otherwise. EE will manually track the energy expenditure.
    TO-DO:
    * Add functionality for allowing easy user interfacing
    * Figure out the weird floating-point bug
    * Review (including test) EE algorithm. Specifications say that we use Acc to get MET. However, algorithm doesn't incorporate this. Need to update?
    * Found an article that also used HR and EE. Perhaps combine the two (use a weighted average of both algorithms)?
    [accelerometer_algorithms.c, main.c, sensors.c]
2022-09-19 Some debugging
    Tried to fix the Energy Expenditure algorithm. Noticed that I was subtracting 1.3 everytime I sampled and not once. Should be fixed.
    Tested with a light jog and found readings to be about 10times higher than expected. Will do research to try and minimize error. May need new (or homemade) model.
    [accelerometer_algorithms.c, main.c, sensors.c]
2022-09-20 Finished Watch/Accelerometer Data Subsystem (v1)
    Finished the "bulk" of the watch and accelerometer data subsystem functions. Mostly just tidying-up code, increasing efficiency, and making it easier to transfer data to main.c for User-MCU subsystem.
    INDIVIDUAL TO-DO:
    * Add functions that return values*100 so they can be displayed on the screen
    * Add a RTC Watchdog that generates an interrupt every minute. This will be used to update time and for calculating EE.
    * Add a function that resets EE and Step counts at midnight.
    * Optimizations (currently using 11.2% of RAM to hold accelerometer data in an array. How to optimize?
    [accelerometer_algorithms.c, i2c.c, main.c]
2022-09-24 Minor Changes
    Added some minor changes, mainly a midnight function that resets EE counter at midnight.
    [accelerometer_algorithms.c, main.c, rtc.c]
2022-09-29 Updated EE Code
    Added functions to allow tracking DAILY vs EXERCISE EE.
    Modified the EE_IEEE function so that it returns the EE multiplied by 100 and casted as an integer (so we can return the data to main and retain two significant digits of data).
    * Add similar functionality to return the EE_exercise value to main (will take 30-40 seconds).
    * Continue to try and figure out how to use RTC interrupts.
    * Once a wearable PCB comes in, create a better model for calculating energy expenditure (maybe make a model based off of the Apple Watch instead of literature METs to obtain better accuracy for spec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
2022-10-04 Working PulseOx
    Pulse Ox is now semi-functional, with data being received from the MAX30102 and stored to a led_array global to the sensors.c file (5 seconds of 30Hz sampled data for Red and Infrared in the form [r0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
    * Algorithms to process the pulse-ox data to get SpO2 and HR.
    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
2022-10-05 Work completely finished SpO2
    Stored the red and infrared sampled data into the array and determined min and max values for R value. Calibrated the data using excel to get the SpO2 value.
2022-10-05 EXTI for Rotary Encoder
    * Wrote external interrupts for rotary encoder and switch.
    * Code all in main. No updates to other functions.
2022-10-05 PCB Files
    Added the starting PCB files for the system PCB. Currently only includes rotary encoder. Will add in the future.
2022-10-06 Cleaner Sensors, Added UART Test Debugging
    Cleaned all the code from Jason's commit (working Pulse Ox). Added a UART variable near the top of main.c. Changing this will turn on or off the UART to allow easier debugging in the future.
2022-10-06 Working Heart Rate
    Finished the Heart Rate algorithm. All sensors are working at the same time. All that is left is the temperature sensor and the user interface. PCB design will also be worked on throughout next week.
2022-10-06 Added Rotary Encoder Test Case
    Added a rotary encoder test case for midterm demo. Will also be used later.
2022-10-06 Working Display, Doesn't Update
    Creates an initial screen with values for different data. Works with all sensors.
    * Compartmentalize the stuff into functions.
    * Add update_display to timer to have screen update ONLY if a value has changed.
    * Add rotary encoder functionality.
    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
    [main.c]
2022-10-06 Working Display!
    Display works and updates once every five seconds. Due to some weird thingy, we get an error unless we reset the LCD each time (likely the sensors take too much time and cause the LCD to have issues). As a result, may give grandma seizures every 5 seconds...
    * Rotary Encoder (Likely will disable everything, adjust stuff, then re-enable everything).
    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
    [main.c]
2022-10-07 Mostly Finished
    All sensors working, display working, encoder allows settings to change. Also resets EE and steps at midnight.
    [main.c]
2022-10-08 Vital Checker Half-Working
    Can detect vital signs bad, but cannot get audio to work from the LC555 (wants higher power).
2022-10-08 Audio Working
    Added code to generate very choppy, annoying audio if a person starts dying. While not as nice sounding as a clean square wave, it does work at alerting the user they are dying.
    * Flash memory
    * PCB
    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
2022-10-12 SCHEMATIC
    Initial schematics
    TO DO:
    * Test-pads
    * Solder jumpers for backup pins
    [ece49022_team44_pcb.kicad_pcb, ece49022_team44_pcb.kicad_sch]
2022-10-13 PCB Manufacturing
    Added the GERBERS, BOM, and POS files for PCB.
    Costs $270 to do one side, $360 to do both. Considering both so it works better, pay out of pocket.
    [ece49022_team44_pcb.csv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]
2022-10-13 All PCB Stuff
    Uploaded changes to PCB (fixed the switch and LEDs). Also GERBERs and CENTROIDS, BOM. Checked on JLCPCB, $220 for build and assembly if only 2 boards.
    Double check silk-screen. Make sure comments look fine.
    Order PCB when fully reviewed.
    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
    [ece49022_team44_pcb-B_Cu.gbr, ece49022_team44_pcb-B_Mask.gbr, ece49022_team44_pcb-B_Paste.gbr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]
2022-10-21 3D File
    3D File for making the 3D printed case
2022-10-26 Semi-Preservative Memory, 32Font, EE
    Able to save memory across software system resets, 32 bit font (kinda, to be fixed later), improved EE algorithm.
    * Prettitize the code (especially in main.c)
    * Better display
    * Case and mechanical engineering
    * Design Document 3
    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
    [accelerometer_algorithms.c, lcd.c, main.c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]
2022-10-27 Fixed 48pt Font
    Small error in 48pt font (only printed 3/4 of a character due to using a uint16t instead of uint32t).
    [lcd.c]
2022-10-28 Testing Python Script
    Custom Font for 0, testing Python script before fixing everything
    [lcd.c]
2022-11-02 16 and 32bit Fonts, Fixed Initial User Data
    Added custom 16bit and 32bit fonts. Also added code that ensures that if reprogramming the chip, user data is not impossible values.
    *48bit font
    *Finalize user interface and settings
    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
    [lcd.c, main.c]
2022-11-15 Adjusted accelerometer code to better detect steps
    NOTE: May need to redo the calorie consumption algorithm, may not.
2022-12-15 Also the rev2 gerbers
